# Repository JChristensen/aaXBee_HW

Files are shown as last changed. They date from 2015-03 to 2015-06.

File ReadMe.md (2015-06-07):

# Double-A XBee Sensor Node #
http://github.com/JChristensen/aaXBee_HW  
ReadMe file  
Jack Christensen Mar 2015  

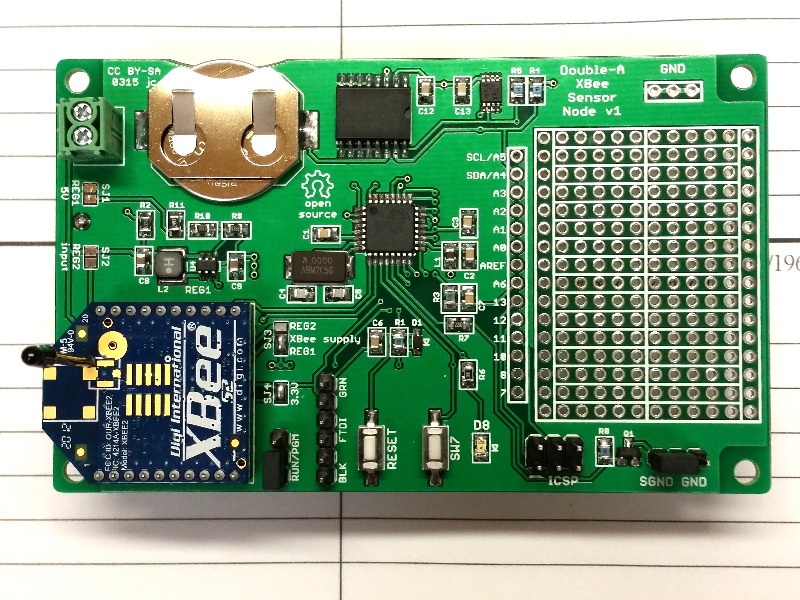
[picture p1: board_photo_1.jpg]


## Introduction ##
A low-power, [Arduino](http://www.arduino.cc/)-compatible [XBee](http://www.digi.com/products/wireless-wired-embedded-solutions/zigbee-rf-modules/zigbee-mesh-module/xbee-zb-module) sensor node that runs on two AA cells. It should run for over a year on a pair of AA alkaline cells (this could be reduced if sensors that require relatively large amounts of power or on-time are used). For an example sketch, see the [aaXBee sketch](https://github.com/JChristensen/GroveStreams/tree/master/examples/aaXBee) in my [GroveStreams library](https://github.com/JChristensen/GroveStreams). The AA XBee Node will send data to an Arduino running the [gsGateway sketch](https://github.com/JChristensen/GroveStreams/tree/master/examples/gsGateway), which forwards it to the [GroveStreams](https://grovestreams.com/) web site. (Also see my blog post, [A GroveStreams Wireless Sensor Network](http://adventuresinarduinoland.blogspot.com/2015/05/a-grovestreams-wireless-sensor-network.html).)

The AA XBee Node includes an accurate real-time clock ([DS3231](http://www.maximintegrated.com/en/products/digital/real-time-clocks/DS3231.html), ±2ppm from 0°C to +40°C) for precise timing of data transmissions and an accurate on-board I2C temperature sensor ([MCP9808](http://www.microchip.com/MCP9808), ±0.25°C typical). A prototyping area is provided for connecting additional sensors. Twelve microcontroller GPIO pins are available to interface with sensors, including the I2C and SPI buses and analog inputs. A pushbutton switch and an LED are available for application use.

## Features ##
The Double-A XBee Sensor Node is a flexible design with three major configuration options based on the voltage and power required by application-specific sensors. One or two boost regulators are used to supply 3.3V to the XBee and either 3.3V or 5V to the MCU and sensors.These configurations are summarized on page 2 of the [aaXBee_BOM.pdf](http://github.com/JChristensen/aaXBee_HW/raw/master/aaXBee_BOM.pdf) file.

Various components are also optional depending on requirements. See page 3 of the [aaXBee_BOM.pdf](http://github.com/JChristensen/aaXBee_HW/raw/master/aaXBee_BOM.pdf) file for comments on optional components.

To conserve power, the AA XBee Node disables the boost regulator(s) and sleeps using the battery voltage directly (sleep current is < 5µA). With the regulator(s) disabled, the MCU's clock speed is reduced to avoid overclocking. Because of this, the board should be programmed with an in-circuit serial programmer (ICSP, e.g. AVRISP mkII, USBtinyISP, USBasp, etc.) as opposed to a bootloader. As part of this approach, specific fuse settings are required, so a custom entry in the Arduino boards.txt file is also recommended as follows:
```
##############################################################
aaDL.name=Double-A Datalogger/Double-A XBee Node
aaDL.upload.protocol=arduino
aaDL.upload.maximum_size=32768
aaDL.bootloader.low_fuses=0x7f
aaDL.bootloader.high_fuses=0xde
aaDL.bootloader.extended_fuses=0x06
aaDL.build.mcu=atmega328p
aaDL.build.f_cpu=8000000L
aaDL.build.core=arduino
aaDL.build.variant=standard
##############################################################
```

## CC BY-SA ##
"Double-A XBee Sensor Node" by Jack Christensen is licensed under [CC BY-SA 4.0](http://creativecommons.org/licenses/by-sa/4.0/).

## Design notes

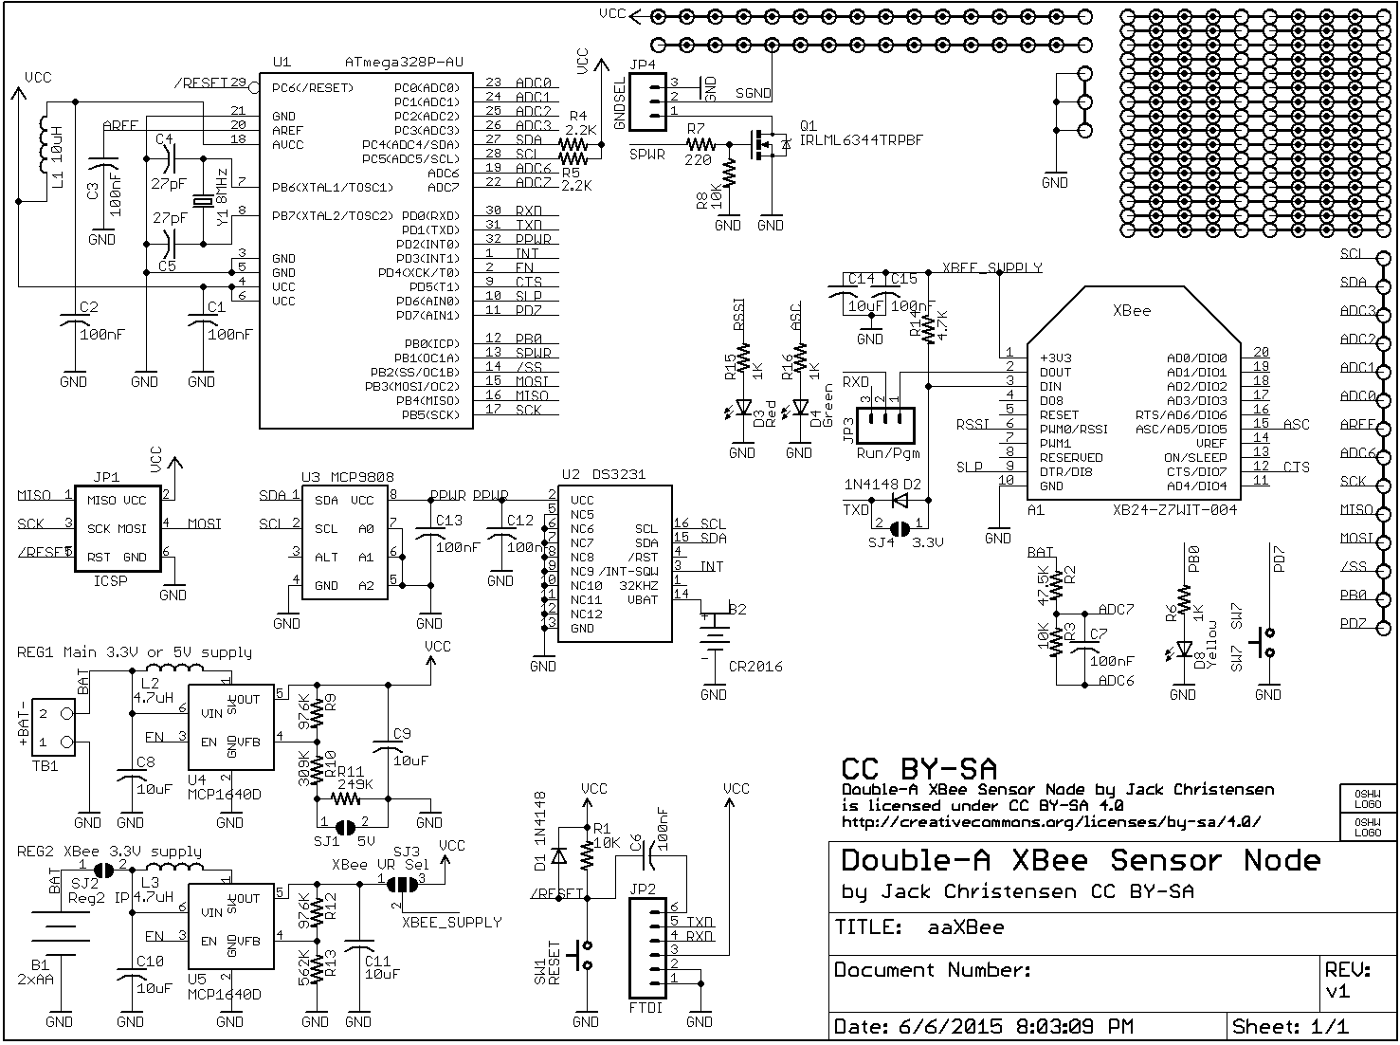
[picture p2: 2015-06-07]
schematic.png

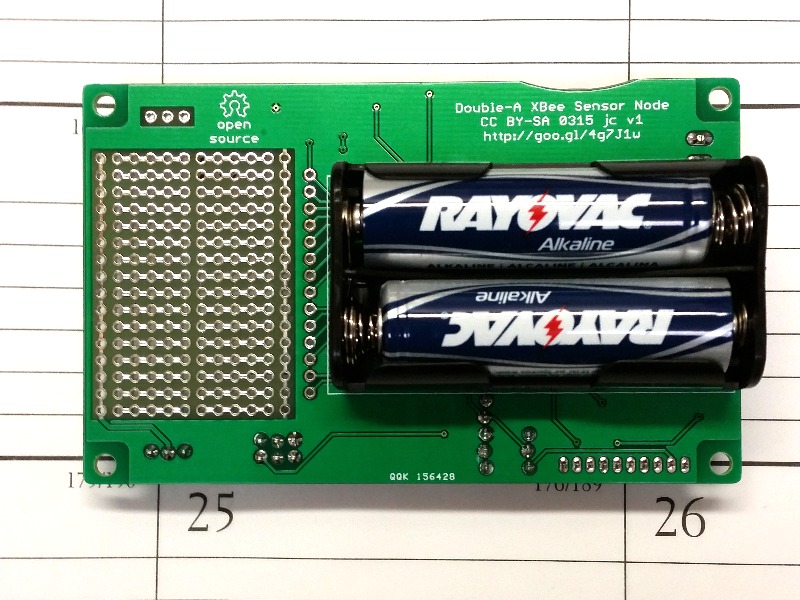
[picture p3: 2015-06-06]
board_photo_2.jpg

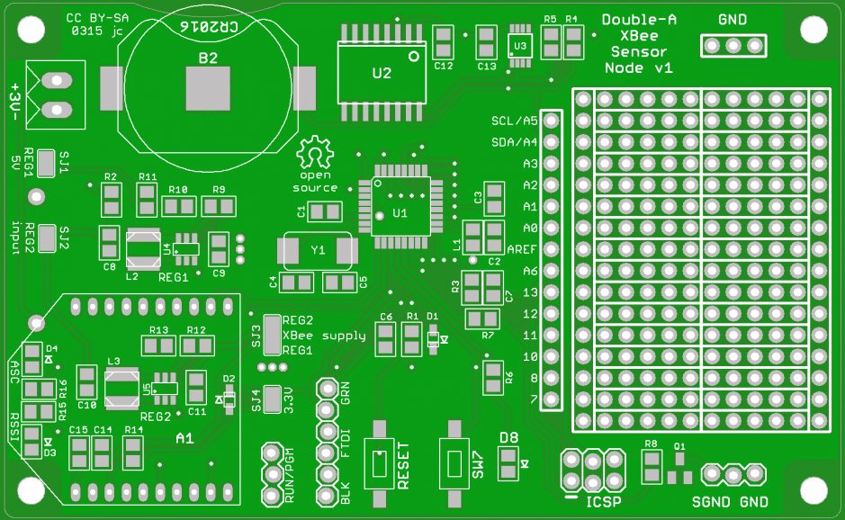
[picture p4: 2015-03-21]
board.png

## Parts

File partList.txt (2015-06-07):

Partlist

Exported from aaXBee.sch at 6/6/2015 8:04:41 PM

EAGLE Version 6.4.0 Copyright (c) 1988-2013 CadSoft

Assembly variant: 

Part     Value          Device                   Package                Library  Sheet

A1       XB24-Z7WIT-004 ULINK_XBEEOVALPADS       XBEE_OVAL_PADS         _jc      1
B1       2xAA           BATTERY-2AANOHOLES       KEYSTONE-2462-NO-HOLES _jc      1
B2       CR2016         COIN-CELL-2016-SMT       BAT-HLD-002-SMT        _jc      1
C1       100nF          C-USM0805                M0805                  _jc      1
C2       100nF          C-USM0805                M0805                  _jc      1
C3       100nF          C-USM0805                M0805                  _jc      1
C4       27pF           C-USM0805                M0805                  _jc      1
C5       27pF           C-USM0805                M0805                  _jc      1
C6       100nF          C-USM0805                M0805                  _jc      1
C7       100nF          C-USM0805                M0805                  _jc      1
C8       10uF           C-USM0805                M0805                  _jc      1
C9       10uF           C-USM0805                M0805                  _jc      1
C10      10uF           C-USM0805                M0805                  _jc      1
C11      10uF           C-USM0805                M0805                  _jc      1
C12      100nF          C-USM0805                M0805                  _jc      1
C13      100nF          C-USM0805                M0805                  _jc      1
C14      10uF           C-USM0805                M0805                  _jc      1
C15      100nF          C-USM0805                M0805                  _jc      1
D1       1N4148         DIODESOD-323F-A          SOD-323F-A             _jc      1
D2       1N4148         DIODESOD-323F-A          SOD-323F-A             _jc      1
D3       Red            LEDD0805A                D0805A                 _jc      1
D4       Green          LEDD0805                 D0805                  _jc      1
D8       Yellow         LEDD0805A                D0805A                 _jc      1
JP1      ICSP           AVR_SPI_PRG_62X3_LOCK    2X3_LOCK               _jc      1
JP2      FTDI           M06LOCK                  1X06_LOCK              SparkFun 1
JP3      Run/Pgm        M03LOCK                  1X03_LOCK              SparkFun 1
JP4      GNDSEL         M03LOCK                  1X03_LOCK              SparkFun 1
L1       10uH           INDUCTORM0805            M0805                  _jc      1
L2       4.7uH          INDUCTORNRS4018          NRS4018                _jc      1
L3       4.7uH          INDUCTORNRS4018          NRS4018                _jc      1
PR1      PROTO-10       PROTO-10                 PROTO-10               _jc      1
PR2      PROTO-10       PROTO-10                 PROTO-10               _jc      1
PR3      PROTO-10       PROTO-10                 PROTO-10               _jc      1
PR4      PROTO-10       PROTO-10                 PROTO-10               _jc      1
PR5      PROTO-10       PROTO-10                 PROTO-10               _jc      1
PR6      PROTO-10       PROTO-10                 PROTO-10               _jc      1
PR7      PROTO-10       PROTO-10                 PROTO-10               _jc      1
PR8      PROTO-10       PROTO-10                 PROTO-10               _jc      1
PR9      PROTO-10       PROTO-10                 PROTO-10               _jc      1
PR10     PROTO-10       PROTO-10                 PROTO-10               _jc      1
PR11     PROTO-10       PROTO-10                 PROTO-10               _jc      1
PR12     PROTO-10       PROTO-10                 PROTO-10               _jc      1
PR13     GND            PROTO-3                  PROTO-3                _jc      1
PR14     PROTO-10       PROTO-10                 PROTO-10               _jc      1
PR15     PROTO-10       PROTO-10                 PROTO-10               _jc      1
PR16     PROTO-10       PROTO-10                 PROTO-10               _jc      1
PR17     PROTO-10       PROTO-10                 PROTO-10               _jc      1
PR18     Proto ground   PROTO-16                 PROTO-16               _jc      1
PR19     Proto Vcc      PROTO-16                 PROTO-16               _jc      1
PR20     Signals        PROTO-14NR               PROTO-14-NR            _jc      1
Q1       IRLML6344TRPBF MOSFET-NCHANNELSOT23     SOT23                  _jc      1
R1       10K            R-US_M0805               M0805                  _jc      1
R2       47.5K          R-US_M0805               M0805                  _jc      1
R3       10K            R-US_M0805               M0805                  _jc      1
R4       2.2K           R-US_M0805               M0805                  _jc      1
R5       2.2K           R-US_M0805               M0805                  _jc      1
R6       1K             R-US_M0805               M0805                  _jc      1
R7       220            R-US_M0805               M0805                  _jc      1
R8       10K            R-US_M0805               M0805                  _jc      1
R9       976K           R-US_M0805               M0805                  _jc      1
R10      309K           R-US_M0805               M0805                  _jc      1
R11      249K           R-US_M0805               M0805                  _jc      1
R12      976K           R-US_M0805               M0805                  _jc      1
R13      562K           R-US_M0805               M0805                  _jc      1
R14      4.7K           R-US_M0805               M0805                  _jc      1
R15      1K             R-US_M0805               M0805                  _jc      1
R16      1K             R-US_M0805               M0805                  _jc      1
SJ1      5V             SJ                       SJ                     jumper   1
SJ2      Reg2 IP        SJ                       SJ                     jumper   1
SJ3      XBee VR Sel    SJ2W                     SJ_2                   jumper   1
SJ4      3.3V           SJ                       SJ                     jumper   1
SW1      RESET          SPST-NO-MCTACT-6X3.5-SMT SWITCH-TACT-6X3.5-SMT  _jc      1
SW7      SW7            SPST-NO-MCTACT-6X3.5-SMT SWITCH-TACT-6X3.5-SMT  _jc      1
TB1      +BAT-          OST-TB-23.5MM            OST-TB-2-3.5MM         _jc      1
U1       ATmega328P-AU  MEGA8-AI                 TQFP32-08              atmel    1
U2       DS3231         DS3231                   SO-16DW                _jc      1
U3       MCP9808        MCP9808                  MSOP8                  _jc      1
U4       MCP1640D       MCP1640                  SOT23-6                _jc      1
U5       MCP1640D       MCP1640                  SOT23-6                _jc      1
Y1       8MHz           CRYSTALABM2              CRYSTAL-ABRACON-ABM2   _jc      1

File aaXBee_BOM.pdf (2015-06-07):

## Double-A XBee Sensor Node v1

Jack Christensen Mar 2015 CC BY-SA
Bill of Materials
Qty | Part # | Mouser # | Mfr. # | Manufacturer | Desc.
1 | A1 | 888-XB24-Z7WIT-004 | XB24-Z7WIT-004 | Digi International | Zigbee / 802.15.4 Modules XBee ZB w/WiredWhip AT Router F/W
2 | A1 | 855-M22-7131042 | M22-7131042 | Harwin | Headers & Wire Housings 10 PIN SIL VERTICAL GOLD+TIN SOCKET
1 | B1 | 534-2462 | 2462 | Keystone Electronics | Cylindrical Battery Contacts, Clips, Holders & Springs 2 CELL AA PC HOLDER
1 | B2 | 658-CR2016 | CR2016 | Panasonic | Coin Cell Battery 3V 20 X 1.6 MM 75mA
1 | B2 | 712-BAT-HLD-002-SMT | BAT-HLD-002-SMT | Linx Technologies | Coin Cell Battery Holders Bat Holder CR2016 Surface Mount
8 | C1,2,3,6,7,12,13,15 581-08055C104K | 08055C104KAT2A | AVX | Multilayer Ceramic Capacitors MLCC - SMD/SMT 0805 0.1uF 50volts X7R 10%
2 | C4,5 | 77-VJ0805A270GXXPBC | VJ0805A270GXXPW1BC Vishay | Multilayer Ceramic Capacitors MLCC - SMD/SMT 0805 27pF 25volts C0G 2%
5 | C8,9,10,11,14 | 81-GRM21BR71A106KA3L GRM21BR71A106KA73L Murata | Multilayer Ceramic Capacitors MLCC - SMD/SMT 0805 10uF 10volts X7R + - 10%
2 | D1,2 | 512-1N4148WS | 1N4148WS | Fairchild Semiconductor | Diodes - General Purpose, Power, Switching Small Signal Diode
1 | D3 | 604-APT2012EC | APT2012EC | Kingbright | Standard LEDs - SMD HI EFF RED WTR CLR
1 | D4 | 604-APT2012SGC | APT2012SGC | Kingbright | Standard LEDs - SMD GREEN WATER CLEAR
1 | D8 | 604-APT2012YC | APT2012YC | Kingbright | Standard LEDs - SMD YELLOW WATER CLEAR
1 | L1 | 963-LBR2012T100K | LBR2012T100K | Taiyo Yuden | Fixed Inductors INDCTR LW RDC WND 0805 10uH 10%
2 | L2,3 | 963-NRS4018T4R7MDGJ | NRS4018T4R7MDGJ | Taiyo Yuden | Fixed Inductors INDCTR LW PROFL WND 4.7uH 20%
1 | Q1 | 942-IRLML6344TRPBF | IRLML6344TRPBF | International Rectifier | MOSFET MOSFT 5.0A 29mOhm 30V 2.5V drv capable
3 | R1,3,8 | 660-RK73H2ATTD1002F | RK73H2ATTD1002F | KOA Speer | Thick Film Resistors - SMD 1/8watts 10Kohms 1%
1 | R10 | 660-RK73H2ATTD3093F | RK73H2ATTD3093F | KOA Speer | Thick Film Resistors - SMD 1/8watts 309Kohms 1%
1 | R11 | 660-RK73H2ATTD2493F | RK73H2ATTD2493F | KOA Speer | Thick Film Resistors - SMD 1/8watts 249Kohms 1%
1 | R13 | 660-RK73H2ATTD5623F | RK73H2ATTD5623F | KOA Speer | Thick Film Resistors - SMD 1/8watts 562Kohms 1%
1 | R14 | 660-RK73H2ATTD4701F | RK73H2ATTD4701F | KOA Speer | Thick Film Resistors - SMD 1/8watts 4.7Kohms 1%
1 | R2 | 660-RK73H2ATTD4752F | RK73H2ATTD4752F | KOA Speer | Thick Film Resistors - SMD 1/8watt 47.5Kohms 1%
2 | R4,5 | 660-RK73H2ATTD2201F | RK73H2ATTD2201F | KOA Speer | Thick Film Resistors - SMD 1/8watts 2.2Kohms 1%
3 | R6,15,16 | 660-RK73H2ATTD1001F | RK73H2ATTD1001F | KOA Speer | Thick Film Resistors - SMD 1/8watts 1Kohms 1%
1 | R7 | 660-RK73H2ATTD2200F | RK73H2ATTD2200F | KOA Speer | Thick Film Resistors - SMD 1/8watts 220ohms 1%
2 | R9,12 | 660-RK73H2ATTD9763F | RK73H2ATTD9763F | KOA Speer | Thick Film Resistors - SMD 1/8watts 976Kohms 1%
2 | SW1,7 | 611-PTS635SL43SMTRLF | PTS635SL43SMTR LFS | C&K Components | Tactile Switches Switch Tact 6X3.5Mm Mom Spst Smd
1 | TB1 | 651-1984617 | 1984617 | Phoenix Contact | Fixed Terminal Blocks PT 1.5/2-3.5H 2POS HRZ 3.5mm SCREW
1 | U1 | 556-ATMEGA328P-AU | ATMEGA328P-AU | Atmel | 8-bit Microcontrollers - MCU 32KB In-system Flash 20MHz 1.8V-5.5V
1 | U2 | 700-DS3231SN#T&R- | DS3231SN#T&R | Maxim Integrated | Real Time Clock Integrated RTC/TCXO/Crystal
1 | U3 | 579-MCP9808T-E/MS | MCP9808T-E/MS | Microchip | Board Mount Temperature Sensors Silicon temp sensor with I2C interface
2 | U4,5 | 579-MCP1640DT-I/CHY | MCP1640DT-I/CHY | Microchip | Voltage Regulators - Switching Regulators 500 kHz 300 mA Syn Boost Converter
1 | Y1 | 815-ABM2-8-D4Y-T | ABM2-8.000MHZ-D4Y-T ABRACON | Crystals 8.0MHz 18pF 30ppm -40C +85C

## Double-A XBee Sensor Node v1

Jack Christensen Mar 2015 CC BY-SA
Solder jumpers determine the configuration as noted.
Config no. | REG1 | REG2 | Notes | SJ1 | SJ2 | SJ3 | SJ4
1 | 3.3V | Absent | Regulator 1 powers the MCU, XBee and sensors. Use when sensors can
| | | run on 3.3V and one regulator supplies sufficient current. Simplest and
| | | most energy efficient configuration. | Open | Open | REG1 | Soldered
2 | 5V | 3.3V | Regulator 1 powers the MCU and sensors with 5V; Regulator 2 powers the XBee with 3.3V. Use only when a sensor requires a 5V supply. Not as energy efficient as Config #1.
Soldered Soldered REG2 | Open
3 | 3.3V | 3.3V | Regulator 1 powers the MCU and sensors with 3.3V; Regulator 2 powers the XBee with 3.3V. Use only when one regulator does not supply sufficient current. Not as energy efficient as Config #1 but more efficient than Config #2.
Open | Soldered REG2 | Soldered

## Double-A XBee Sensor Node v1

Jack Christensen Mar 2015 CC BY-SA
Optional components, X = required.
Part | Value | Config 1 | Config 2 | Config 3 | Notes
A1 | XB24-Z7WIT-004 | X | X | X
B1 | 2xAA | optional | optional | optional Either B1 or TB1 must supply the main 3VDC power for the circuit (they
| | | | | are wired in parallel).
B2 | CR2016 | X | X | X
C1 | 100nF | X | X | X
C2 | 100nF | X | X | X
C3 | 100nF | X | X | X
C4 | 27pF | X | X | X
C5 | 27pF | X | X | X
C6 | 100nF | optional | optional | optional Required for serial bootloader programming. See Note 1.
C7 | 100nF | optional | optional | optional Required to measure battery voltage via ADC6 and ADC7.
C8 | 10uF | X | X | X
C9 | 10uF | X | X | X
C10 | 10uF | optional | X | X | See Note 2.
C11 | 10uF | optional | X | X | See Note 2.
C12 | 100nF | X | X | X
C13 | 100nF | optional | optional | optional Required if MCP9808 temperature sensor is installed.
C14 | 10uF | X | X | X
C15 | 100nF | X | X | X
D1 | 1N4148 | optional | optional | optional Required for serial bootloader programming. See Note 1.
D2 | 1N4148 | optional | X | optional See Note 2.
D3 | Red | optional | optional | optional May be used for diagnostic purposes.
D4 | Green | optional | optional | optional May be used for diagnostic purposes.
D8 | Yellow | optional | optional | optional May be used for diagnostic purposes.
JP1 | ICSP | X | X | X
JP2 | FTDI | optional | optional | optional See Note 1.
JP3 | Run/Pgm | optional | optional | optional The middle pad can be hardwired to the run pad if only ICSP programming
| | | | | will be used.
JP4 | GNDSEL | optional | optional | optional Can be hardwired if desired. See Note 3.
L1 | 10uH | X | X | X
L2 | 4.7uH | X | X | X
L3 | 4.7uH | optional | X | X | See Note 2.
Q1 | IRLML6344TRPBF | optional | optional | optional Required for switched ground. See Note 3.
R1 | 10K | X | X | X
R2 | 47.5K | optional | optional | optional Required to measure battery voltage via ADC6 and ADC7.
R3 | 10K | optional | optional | optional Required to measure battery voltage via ADC6 and ADC7.
R4 | 2.2K | X | X | X
R5 | 2.2K | X | X | X
R6 | 1K | optional | optional | optional Required if D8 is installed.
R7 | 220 | optional | optional | optional Required for switched ground. See Note 3.
R8 | 10K | optional | optional | optional Required for switched ground. See Note 3.

R9 | 976K | X | X | X
R10 | 309K | X | X | X
R11 | 249K | X | X | X
R12 | 976K | optional | X | X | See Note 2.
R13 | 562K | optional | X | X | See Note 2.
R14 | 4.7K | optional | X | optional See Note 2.
R15 | 1K | optional | optional | optional Required if D3 is installed.
R16 | 1K | optional | optional | optional Required if D4 is installed.
SW1 | RESET | X | X | X
SW7 | SW7 | optional | optional | optional For user application.
TB1 | +BAT- | optional | optional | optional Either B1 or TB1 must supply the main 3VDC power for the circuit (they
| | | | | are wired in parallel).
U1 | ATmega328P-AU | X | X | X
U2 | DS3231 | X | X | X
U3 | MCP9808 | optional | optional | optional Accurate (±0.25°C typical) temperature sensor.
U4 | MCP1640D | X | X | X | Boost regulator #1.
U5 | MCP1640D | optional | X | X | Boost regulator #2.
Y1 | 8MHz | X | X | X
Note 1. | The FTDI header is supplied primarily to allow debugging via the serial port. Because the AA XBee Node changes the
system clock frequency during normal operation, programming via ICSP is the intended method. However, it may be possible to configure a serial bootloader which operates with a 1MHz system clock speed and a proportionally
| lower baud rate.
Note 2. | These components marked as optional may be installed to allow ease of changing between configurations by just
setting the solder jumpers accordingly.

Note 3. Sensors and other circuitry installed in the prototyping area should normally use a switched ground, i.e. the ground is connected via a low-side MOSFET switch (Q1). This usually results in minimum current consumption during sleep intervals. However, the prototyping area ground can optionally be connected to the hard circuit ground via the three-pin header near Q1.

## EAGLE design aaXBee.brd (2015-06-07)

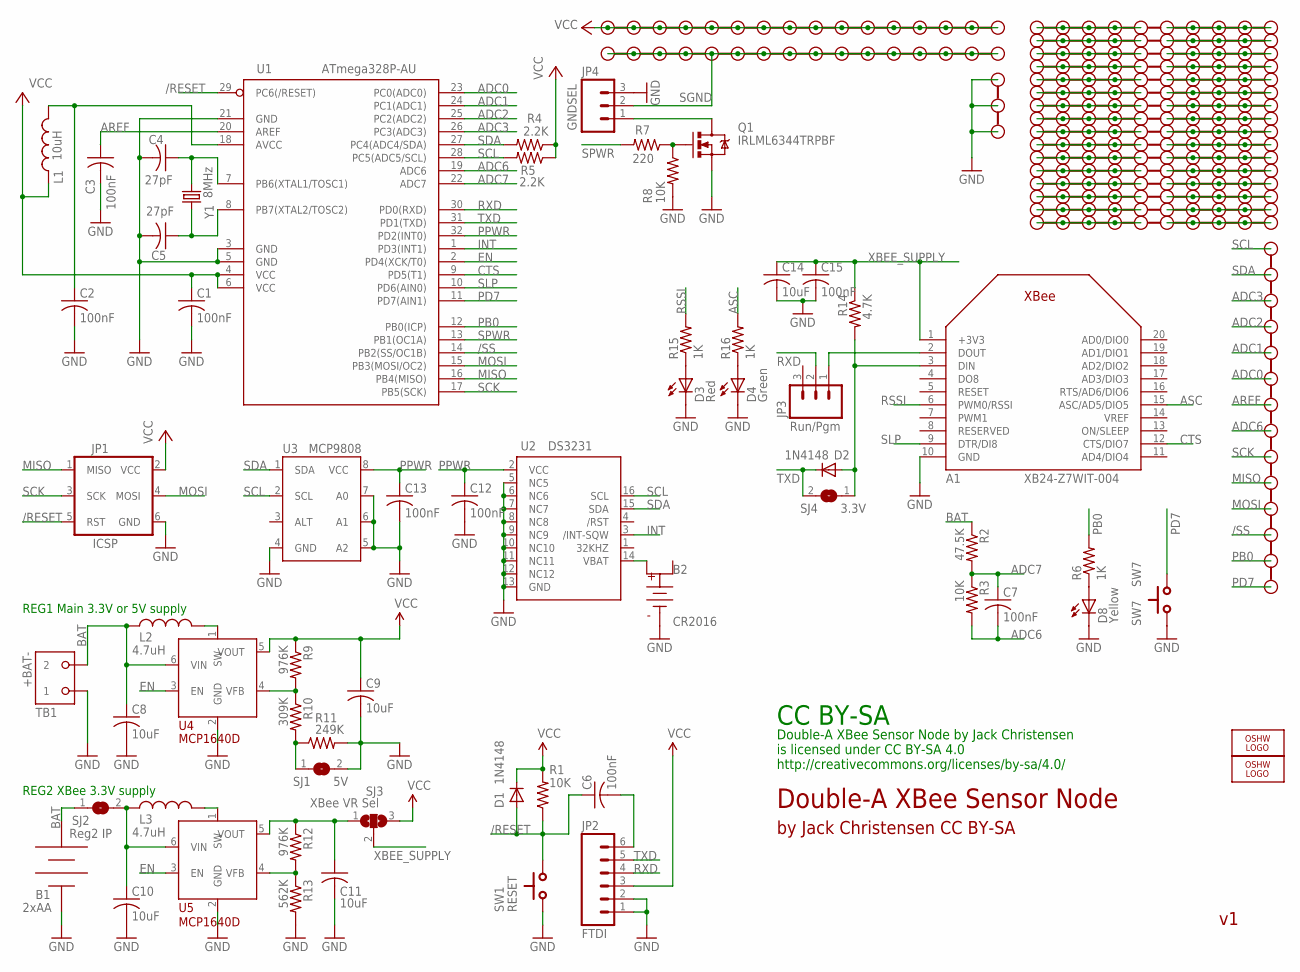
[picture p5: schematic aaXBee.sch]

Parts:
A1: XB24-Z7WIT-004; XBEE_OVAL_PADS
B1: 2xAA; KEYSTONE-2462-NO-HOLES
B2: CR2016; BAT-HLD-002-SMT
C1, C2, C3, C6, C7, C12, C13, C15: 100nF; M0805
C4, C5: 27pF; M0805
C8, C9, C10, C11, C14: 10uF; M0805
D1, D2: 1N4148; SOD-323F-A
D3: Red; D0805A
D4: Green; D0805
D8: Yellow; D0805A
JP1: ICSP; 2X3_LOCK
JP2: FTDI; 1X06_LOCK
JP3: Run/Pgm; 1X03_LOCK
JP4: GNDSEL; 1X03_LOCK
L1: 10uH; M0805
L2, L3: 4.7uH; NRS4018
LOGO1, LOGO2: OSHW_LOGO_8MILX0150-NT; OSHW_8X150_NOTEXT
PR1, PR2, PR3, PR4, PR5, PR6, PR7, PR8, PR9, PR10, PR11, PR12, PR14, PR15, PR16, PR17: PROTO-10
PR13: GND; PROTO-3
PR18: Proto ground; PROTO-16
PR19: Proto Vcc; PROTO-16
PR20: Signals; PROTO-14-NR
Q1: IRLML6344TRPBF; SOT23
R1, R3, R8: 10K; M0805
R2: 47.5K; M0805
R4, R5: 2.2K; M0805
R6, R15, R16: 1K; M0805
R7: 220; M0805
R9, R12: 976K; M0805
R10: 309K; M0805
R11: 249K; M0805
R13: 562K; M0805
R14: 4.7K; M0805
SJ1: 5V; SJ
SJ2: Reg2 IP; SJ
SJ3: XBee VR Sel; SJ_2
SJ4: 3.3V; SJ
SW1: RESET; SWITCH-TACT-6X3.5-SMT
SW7: SW7; SWITCH-TACT-6X3.5-SMT
TB1: +BAT-; OST-TB-2-3.5MM
U1: ATmega328P-AU; TQFP32-08
U2: DS3231; SO-16DW
U3: MCP9808; MSOP8
U4, U5: MCP1640D; SOT23-6
Y1: 8MHz; CRYSTAL-ABRACON-ABM2

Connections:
/RESET: C6.1, D1.A, JP1.5 (RST), R1.1, SW1.P$1, U1.29 (PC6(/RESET))
/SS: PR20.3, U1.14 (PB2(SS/OC1B))
ADC0: PR20.9, U1.23 (PC0(ADC0))
ADC1: PR20.10, U1.24 (PC1(ADC1))
ADC2: PR20.11, U1.25 (PC2(ADC2))
ADC3: PR20.12, U1.26 (PC3(ADC3))
ADC6: C7.2, PR20.7, R3.2, U1.19 (ADC6)
ADC7: C7.1, R2.2, R3.1, U1.22 (ADC7)
AREF: C3.1, PR20.8, U1.20 (AREF)
ASC: A1.15 (ASC/AD5/DIO5), R16.2
BAT: B1.POS, C8.1, L2.P$1 (1), R2.1, SJ2.1, TB1.P$2 (2), U4.6 (VIN)
CTS: A1.12 (CTS/DIO7), U1.9 (PD5(T1))
EN: U1.2 (PD4(XCK/T0)), U4.3 (EN), U5.3 (EN)
GND: A1.10 (GND), B1.NEG, B2.NEG (B-), C1.2, C2.2, C3.2, C4.2, C5.2, C8.2, C9.2, C10.2, C11.2, C12.2, C13.2, C14.2, C15.2, D3.K (C), D4.K (C), D8.K (C), JP1.6 (GND), JP2.1, JP2.2, JP4.3, PR13.1, PR13.2, PR13.3, Q1.2 (S), R8.2, R11.2, R13.2, SJ1.2, SW1.P$2, SW7.P$2, TB1.P$1 (1), U1.3 (GND), U1.5 (GND), U1.21 (GND), U2.5 (NC5), U2.6 (NC6), U2.7 (NC7), U2.8 (NC8), U2.9 (NC9), U2.10 (NC10), U2.11 (NC11), U2.12 (NC12), U2.13 (GND), U3.4 (GND), U3.5 (A2), U3.6 (A1), U3.7 (A0), U4.2 (GND), U5.2 (GND)
INT: U1.1 (PD3(INT1)), U2.3 (/INT-SQW)
MISO: JP1.1 (MISO), PR20.5, U1.16 (PB4(MISO))
MOSI: JP1.4 (MOSI), PR20.4, U1.15 (PB3(MOSI/OC2))
unnamed: B2.POS1, U2.14 (VBAT)
unnamed: D8.A, R6.1
unnamed: PR1.6, PR1.7, PR1.8, PR1.9, PR1.10
unnamed: PR5.6, PR5.7, PR5.8, PR5.9, PR5.10
unnamed: R9.2, R10.1, U4.4 (VFB)
unnamed: L2.P$2 (2), U4.1 (SW)
unnamed: R10.2, R11.1, SJ1.1
unnamed: PR2.6, PR2.7, PR2.8, PR2.9, PR2.10
unnamed: PR3.6, PR3.7, PR3.8, PR3.9, PR3.10
unnamed: R12.2, R13.1, U5.4 (VFB)
unnamed: L3.P$2 (2), U5.1 (SW)
unnamed: PR4.6, PR4.7, PR4.8, PR4.9, PR4.10
unnamed: PR6.6, PR6.7, PR6.8, PR6.9, PR6.10
unnamed: PR7.1, PR7.2, PR7.3, PR7.4, PR7.5
unnamed: PR8.1, PR8.2, PR8.3, PR8.4, PR8.5
unnamed: PR9.1, PR9.2, PR9.3, PR9.4, PR9.5
unnamed: PR10.1, PR10.2, PR10.3, PR10.4, PR10.5
unnamed: PR11.1, PR11.2, PR11.3, PR11.4, PR11.5
unnamed: PR12.1, PR12.2, PR12.3, PR12.4, PR12.5
unnamed: PR1.1, PR1.2, PR1.3, PR1.4, PR1.5
unnamed: PR2.1, PR2.2, PR2.3, PR2.4, PR2.5
unnamed: Q1.1 (G), R7.1, R8.1
unnamed: PR3.1, PR3.2, PR3.3, PR3.4, PR3.5
unnamed: PR4.1, PR4.2, PR4.3, PR4.4, PR4.5
unnamed: PR6.1, PR6.2, PR6.3, PR6.4, PR6.5
unnamed: PR7.6, PR7.7, PR7.8, PR7.9, PR7.10
unnamed: PR5.1, PR5.2, PR5.3, PR5.4, PR5.5
unnamed: PR8.6, PR8.7, PR8.8, PR8.9, PR8.10
unnamed: PR9.6, PR9.7, PR9.8, PR9.9, PR9.10
unnamed: PR10.6, PR10.7, PR10.8, PR10.9, PR10.10
unnamed: PR11.6, PR11.7, PR11.8, PR11.9, PR11.10
unnamed: PR12.6, PR12.7, PR12.8, PR12.9, PR12.10
unnamed: C10.1, L3.P$1 (1), SJ2.2, U5.6 (VIN)
unnamed: JP4.1, Q1.3 (D)
unnamed: A1.3 (DIN), D2.A, R14.2, SJ4.1
unnamed: A1.2 (DOUT), JP3.1
unnamed: C11.1, R12.1, SJ3.1, U5.5 (VOUT)
unnamed: PR14.1, PR14.2, PR14.3, PR14.4, PR14.5
unnamed: D3.A, R15.1
unnamed: D4.A, R16.1
unnamed: C4.1, U1.7 (PB6(XTAL1/TOSC1)), Y1.P$2 (2)
unnamed: C5.1, U1.8 (PB7(XTAL2/TOSC2)), Y1.P$1 (1)
unnamed: PR14.6, PR14.7, PR14.8, PR14.9, PR14.10
unnamed: C2.1, L1.2, U1.18 (AVCC)
unnamed: PR15.1, PR15.2, PR15.3, PR15.4, PR15.5
unnamed: PR15.6, PR15.7, PR15.8, PR15.9, PR15.10
unnamed: PR16.1, PR16.2, PR16.3, PR16.4, PR16.5
unnamed: PR16.6, PR16.7, PR16.8, PR16.9, PR16.10
unnamed: PR17.1, PR17.2, PR17.3, PR17.4, PR17.5
unnamed: PR17.6, PR17.7, PR17.8, PR17.9, PR17.10
PB0: PR20.2, R6.2, U1.12 (PB0(ICP))
PD7: PR20.1, SW7.P$1, U1.11 (PD7(AIN1))
PPWR: C12.1, C13.1, U1.32 (PD2(INT0)), U2.2 (VCC), U3.8 (VCC)
RSSI: A1.6 (PWM0/RSSI), R15.2
RST: C6.2, JP2.6
RXD: JP2.4, JP3.2, U1.30 (PD0(RXD))
SCK: JP1.3 (SCK), PR20.6, U1.17 (PB5(SCK))
SCL: PR20.14, R5.2, U1.28 (PC5(ADC5/SCL)), U2.16 (SCL), U3.2 (SCL)
SDA: PR20.13, R4.2, U1.27 (PC4(ADC4/SDA)), U2.15 (SDA), U3.1 (SDA)
SGND: JP4.2, PR18.1, PR18.2, PR18.3, PR18.4, PR18.5, PR18.6, PR18.7, PR18.8, PR18.9, PR18.10, PR18.11, PR18.12, PR18.13, PR18.14, PR18.15, PR18.16
SLP: A1.9 (DTR/DI8), U1.10 (PD6(AIN0))
SPWR: R7.2, U1.13 (PB1(OC1A))
TXD: D2.K, JP2.5, SJ4.2, U1.31 (PD1(TXD))
VCC: C1.1, C9.1, D1.K, JP1.2 (VCC), JP2.3, L1.1, PR19.1, PR19.2, PR19.3, PR19.4, PR19.5, PR19.6, PR19.7, PR19.8, PR19.9, PR19.10, PR19.11, PR19.12, PR19.13, PR19.14, PR19.15, PR19.16, R1.2, R4.1, R5.1, R9.1, SJ3.3, U1.4 (VCC), U1.6 (VCC), U4.5 (VOUT)
XBEE_SUPPLY: A1.1 (+3V3), C14.1, C15.1, R14.1, SJ3.2

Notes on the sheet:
Double-A XBee Sensor Node
by Jack Christensen CC BY-SA
Double-A XBee Sensor Node by Jack Christensen is licensed under CC BY-SA 4.0 http://creativecommons.org/licenses/by-sa/4.0/
CC BY-SA
REG1 Main 3.3V or 5V supply
REG2 XBee 3.3V supply

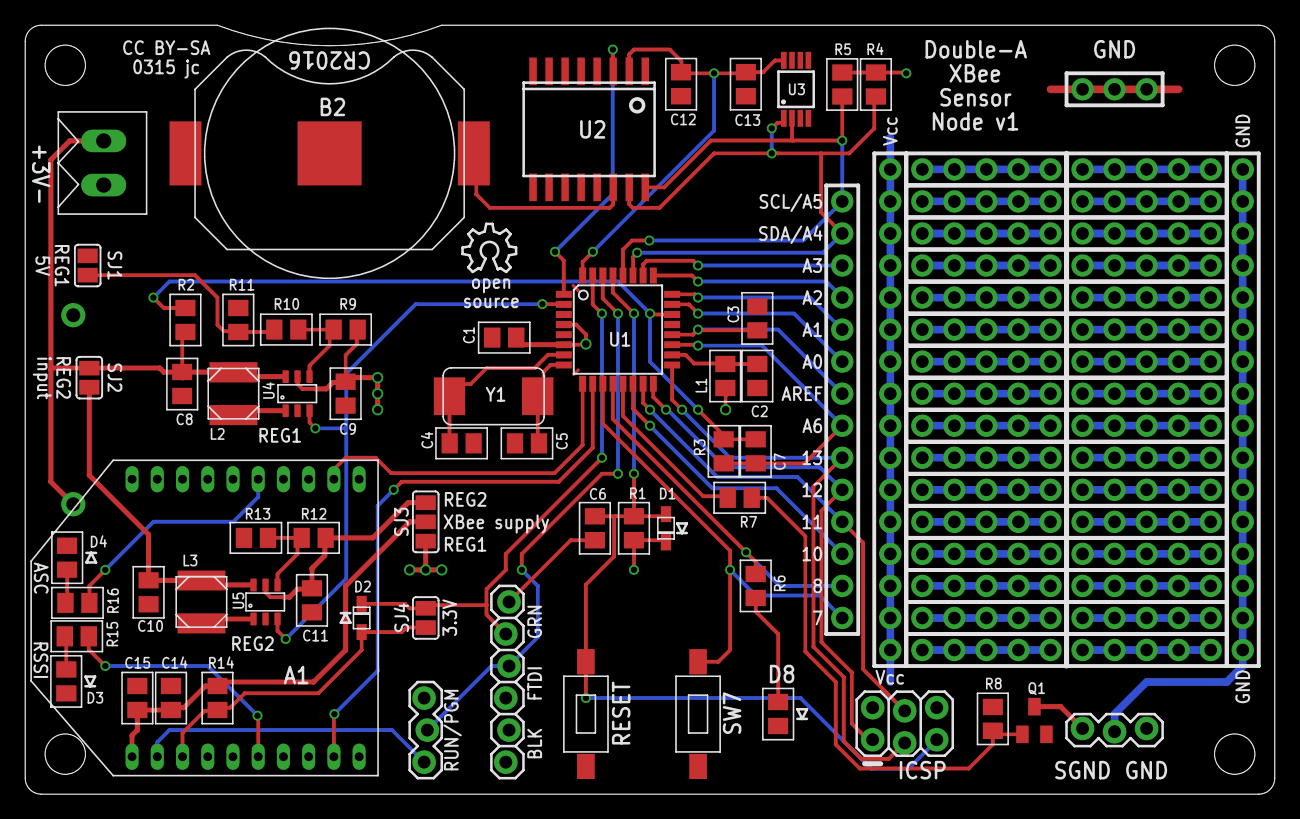
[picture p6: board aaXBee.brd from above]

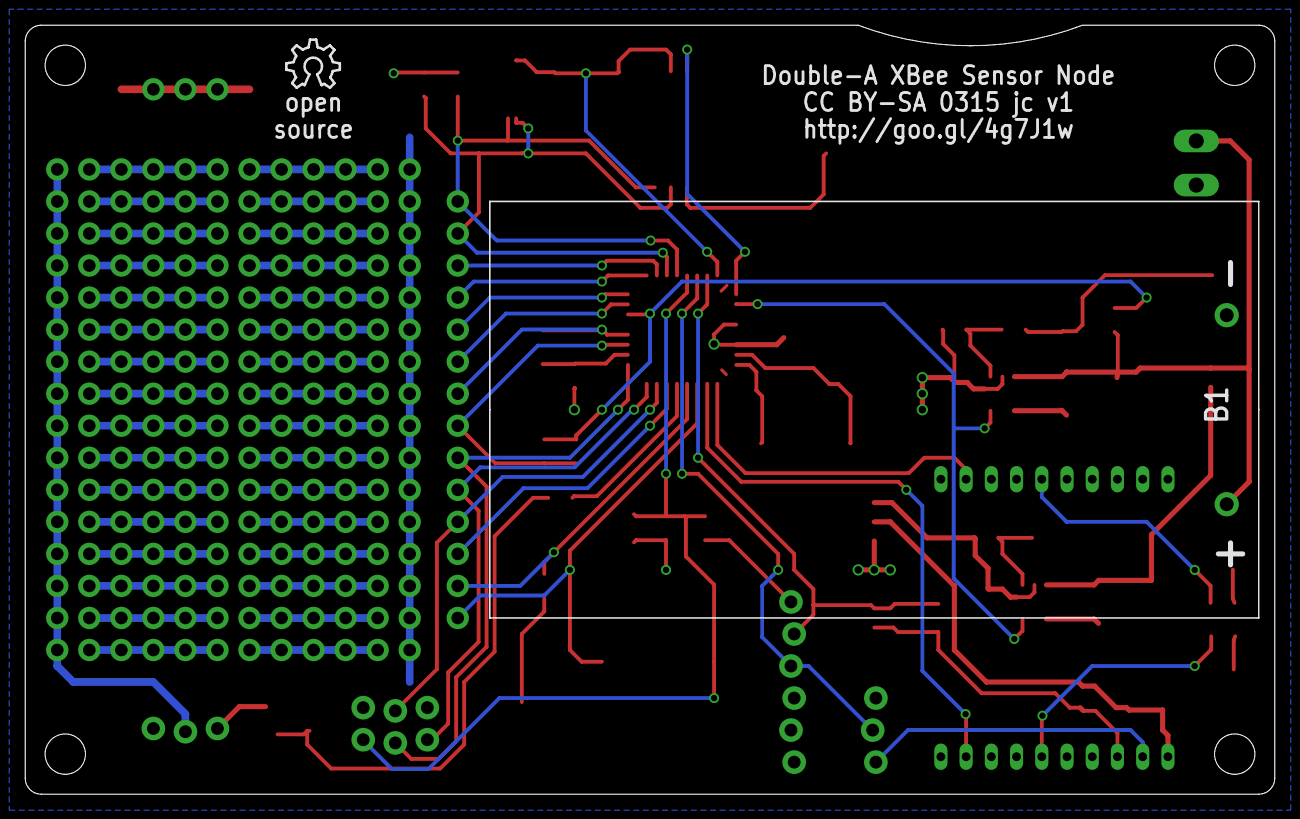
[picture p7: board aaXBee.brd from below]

Board: 2 copper layers, 99.1 x 61.0 mm, 82 parts (2 on the bottom side), 82 nets.

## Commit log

2015-01-18 Initial commit.
    [aaXBee.brd, aaXBee.sch]
2015-02-05 First reasonably complete routing.
    [aaXBee.brd, aaXBee.sch]
2015-02-23 Routing complete.
    [aaXBee.brd, aaXBee.sch]
2015-02-28 Tweak a few traces.
    [aaXBee.brd, aaXBee.sch]
2015-02-28 Rename some components to be sequential. Cosmetic adjustments to schematic.
    [aaXBee.brd, aaXBee.sch]
2015-03-20 As sent to fab.
    [aaXBee.brd, aaXBee.sch, aaXBee_BOM.xlsx]
2015-03-20 Update doc files, board and schematic images.
2015-03-21 New board image.
2015-03-21 Add Vcc & GND labels to proto area.
    [aaXBee.brd]
2015-03-21 Add configuration and optional component information to the Excel BoM workbook.
    [aaXBee_BOM.xlsx]
2015-06-06 Improved footprint for U3, change Q1 to Si2302CDS, added documentation and photos.
    [aaXBee.brd, aaXBee.sch, aaXBee_BOM.xlsx]
2015-06-07 Change Q1 to IRLML6344TRPBF.
    [aaXBee.brd, aaXBee.sch, aaXBee_BOM.xlsx]

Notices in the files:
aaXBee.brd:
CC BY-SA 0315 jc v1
